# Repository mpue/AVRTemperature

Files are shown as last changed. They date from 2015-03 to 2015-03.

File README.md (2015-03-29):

AVRTemperature
==============================

Measuring temperature with the ATMega8 and a TSIC 0306. This version is interrupt driven.

Hardware: ATMega8/16MHz
 
This program measures the temperature of a TSIC0306 temperature sensor, which is
connected to the INT1 pin. The sensor itself is powered via the ZACPIN defined
in zacwire.h

At the beginning the TSIC is powered on and when the first falling edge occurs the measurement
starts. Timer 1 is started in normal mode. When the first rising edge occurs the timer is being
stopped and the value from the TCNT1 register is taken as strobe value.

From now on on each falling edge of the INT1 pin the timer1 is started in ctc mode. Each time
the OCR1A register is equal to the timer value, the TIMER1_COMPA_vect interrupt service routine
is being triggered. This is exactly the 50% duty cycle time which is needed to detect the state
of each bit.

After measuring the MSB the parity bit and the stop bit are being skipped, then the measurement
for the LSB continues, at the end the parity bit is skipped again and the measurement is complete.
The whole thing is driven by a "state machine" like mechanism. This in fact not a real state machine,
since we have no events, rules or transitions.
 
This code doesn't represent the most efficient solution. The goal was to understand the zacwire protocol
and to write human readable code. Feel free to improve the code and give suggestions.

Usage
==============================
You must have avrdude and avr-gcc installed. Use an ATMega8@16MHz, given the attached schematic.

Program with:

make program

You'll have to adjust your programmer before. Don't mess up the fuses!

Schematics and board layout resides in the eagle folder.

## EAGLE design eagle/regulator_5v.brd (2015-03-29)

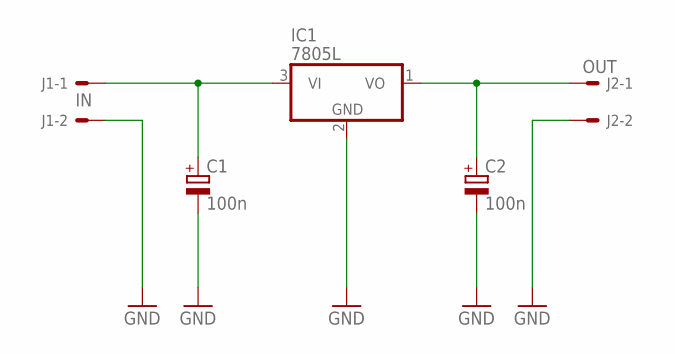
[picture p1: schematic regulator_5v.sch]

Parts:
C1, C2: 100n; TT2D5
IC1: 7805L; TO92
J1: IN; 6410-02
J2: OUT; 6410-02

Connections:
GND: C1.-, C2.-, IC1.2 (GND), J1.2, J2.2
unnamed: C1.+, IC1.3 (VI), J1.1
unnamed: C2.+, IC1.1 (VO), J2.1

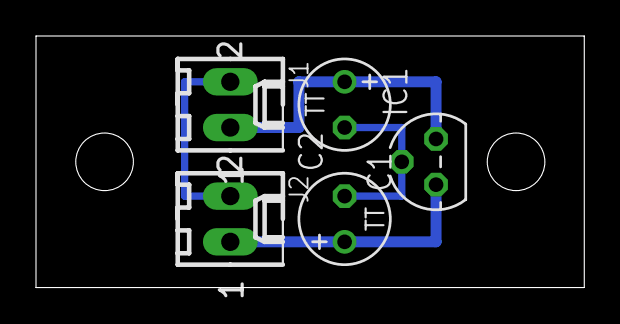
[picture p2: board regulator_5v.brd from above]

Board: 2 copper layers, 30.5 x 14.0 mm, 5 parts (0 on the bottom side), 3 nets.

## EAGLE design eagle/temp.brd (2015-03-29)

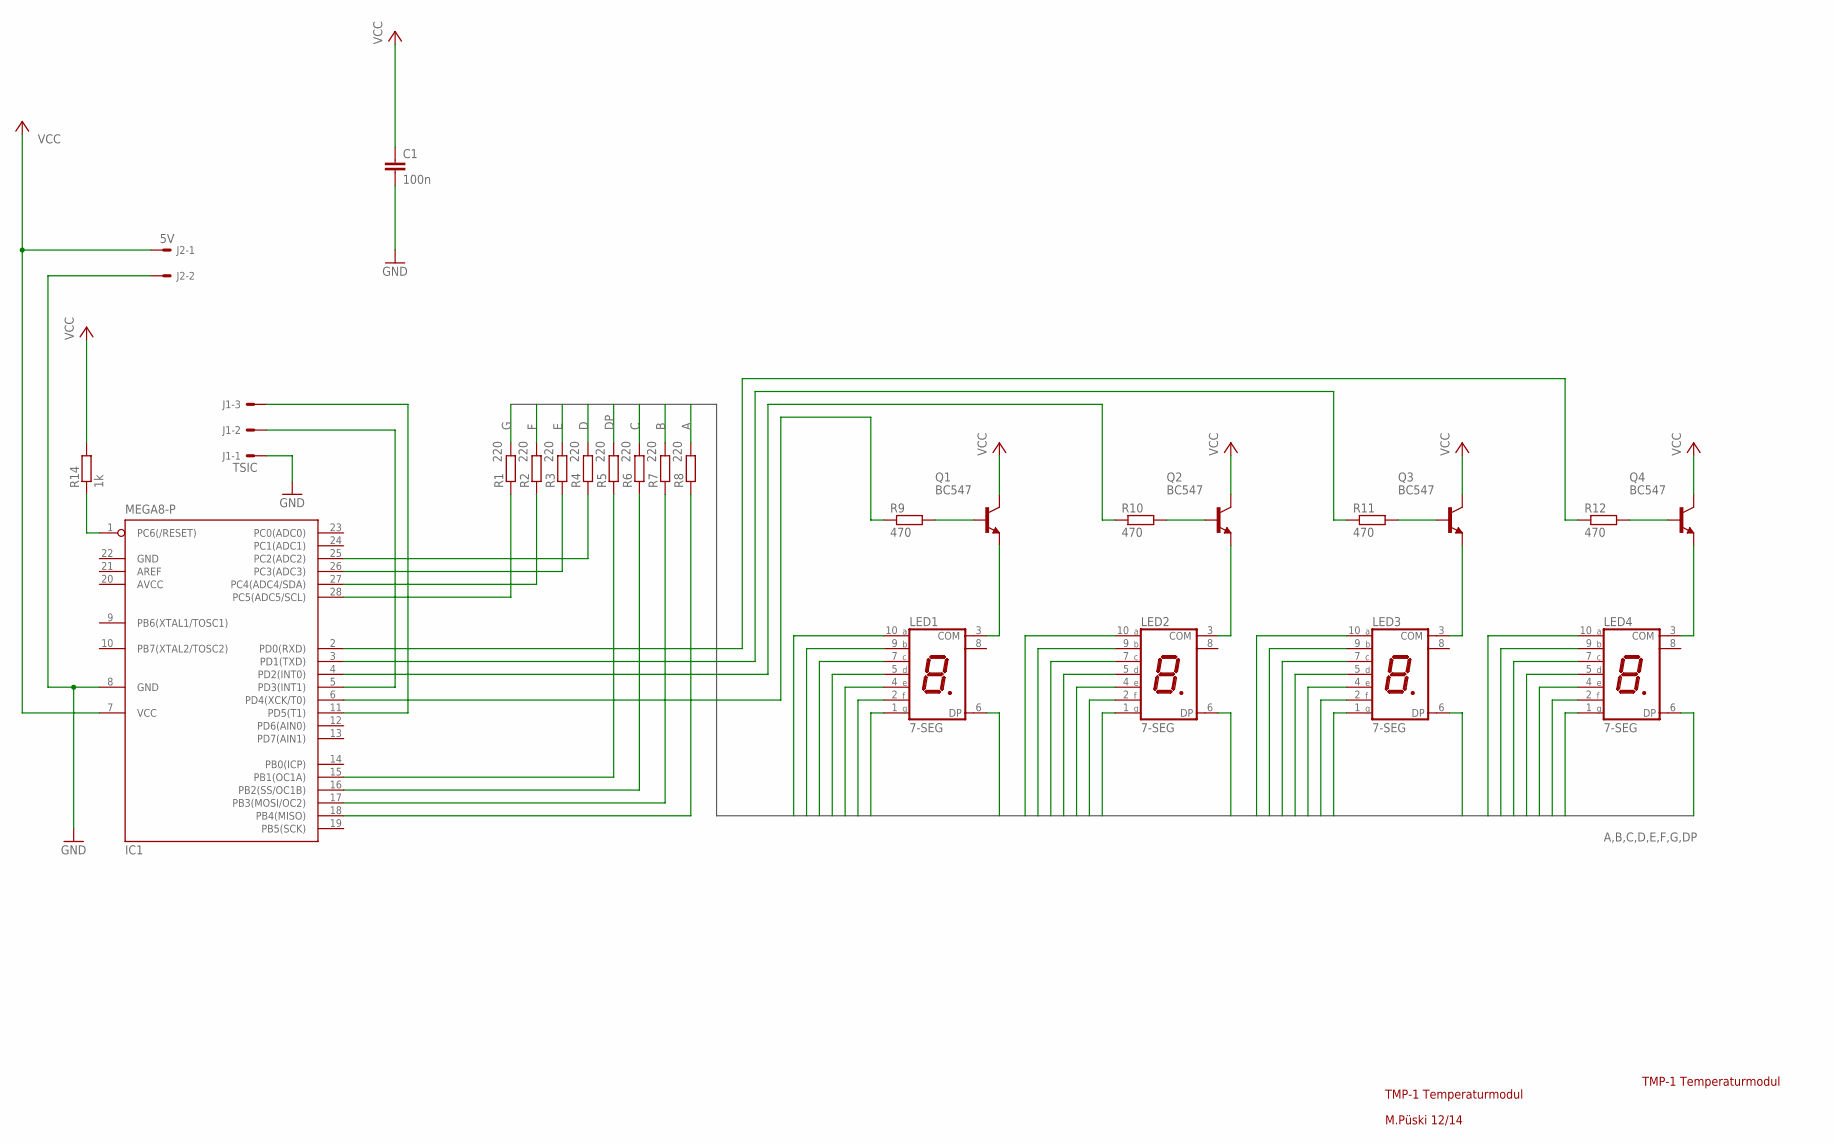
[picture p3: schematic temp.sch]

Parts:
C1: 100n; C050-024X044
IC1: MEGA8-P; DIL28-3
J1: TSIC; 6410-03
J2: 5V; 6410-02
LED1, LED2, LED3, LED4: 7-SEG; SA39-11SRWA
Q1, Q2, Q3, Q4: BC547; TO92
R1, R2, R4, R5, R6, R7, R8: 220; 0204/7
R3: 220; 0204V
R9, R10, R12: 470; 0204/7
R11: 470; 0204V
R14: 1k; 0204/7

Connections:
A: LED1.10 (A), LED2.10 (A), LED3.10 (A), LED4.10 (A), R8.2
AVCC: IC1.20 (AVCC)
B: LED1.9 (B), LED2.9 (B), LED3.9 (B), LED4.9 (B), R7.2
C: LED1.7 (C), LED2.7 (C), LED3.7 (C), LED4.7 (C), R6.2
D: LED1.5 (D), LED2.5 (D), LED3.5 (D), LED4.5 (D), R4.2
DP: LED1.6 (DP), LED2.6 (DP), LED3.6 (DP), LED4.6 (DP), R5.2
E: LED1.4 (E), LED2.4 (E), LED3.4 (E), LED4.4 (E), R3.2
F: LED1.2 (F), LED2.2 (F), LED3.2 (F), LED4.2 (F), R2.2
G: LED1.1 (G), LED2.1 (G), LED3.1 (G), LED4.1 (G), R1.2
GND: C1.2, IC1.8 (GND), IC1.22 (GND), J1.1, J2.2
unnamed: IC1.27 (PC4(ADC4/SDA)), R2.1
unnamed: IC1.26 (PC3(ADC3)), R3.1
unnamed: IC1.25 (PC2(ADC2)), R4.1
unnamed: IC1.15 (PB1(OC1A)), R5.1
unnamed: IC1.16 (PB2(SS/OC1B)), R6.1
unnamed: IC1.17 (PB3(MOSI/OC2)), R7.1
unnamed: IC1.18 (PB4(MISO)), R8.1
unnamed: Q1.2 (B), R9.2
unnamed: Q2.2 (B), R10.2
unnamed: Q3.2 (B), R11.2
unnamed: LED3.3 (COM), Q3.1 (E)
unnamed: LED2.3 (COM), Q2.1 (E)
unnamed: LED1.3 (COM), Q1.1 (E)
unnamed: IC1.2 (PD0(RXD)), R12.1
unnamed: IC1.3 (PD1(TXD)), R11.1
unnamed: IC1.4 (PD2(INT0)), R10.1
unnamed: IC1.28 (PC5(ADC5/SCL)), R1.1
unnamed: Q4.2 (B), R12.2
unnamed: LED4.3 (COM), Q4.1 (E)
unnamed: IC1.1 (PC6(/RESET)), R14.1
unnamed: IC1.6 (PD4(XCK/T0)), R9.1
unnamed: IC1.11 (PD5(T1)), J1.3
unnamed: IC1.5 (PD3(INT1)), J1.2
VCC: C1.1, IC1.7 (VCC), J2.1, Q1.3 (C), Q2.3 (C), Q3.3 (C), Q4.3 (C), R14.2

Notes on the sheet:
TMP-1 Temperaturmodul
M.Püski 12/14

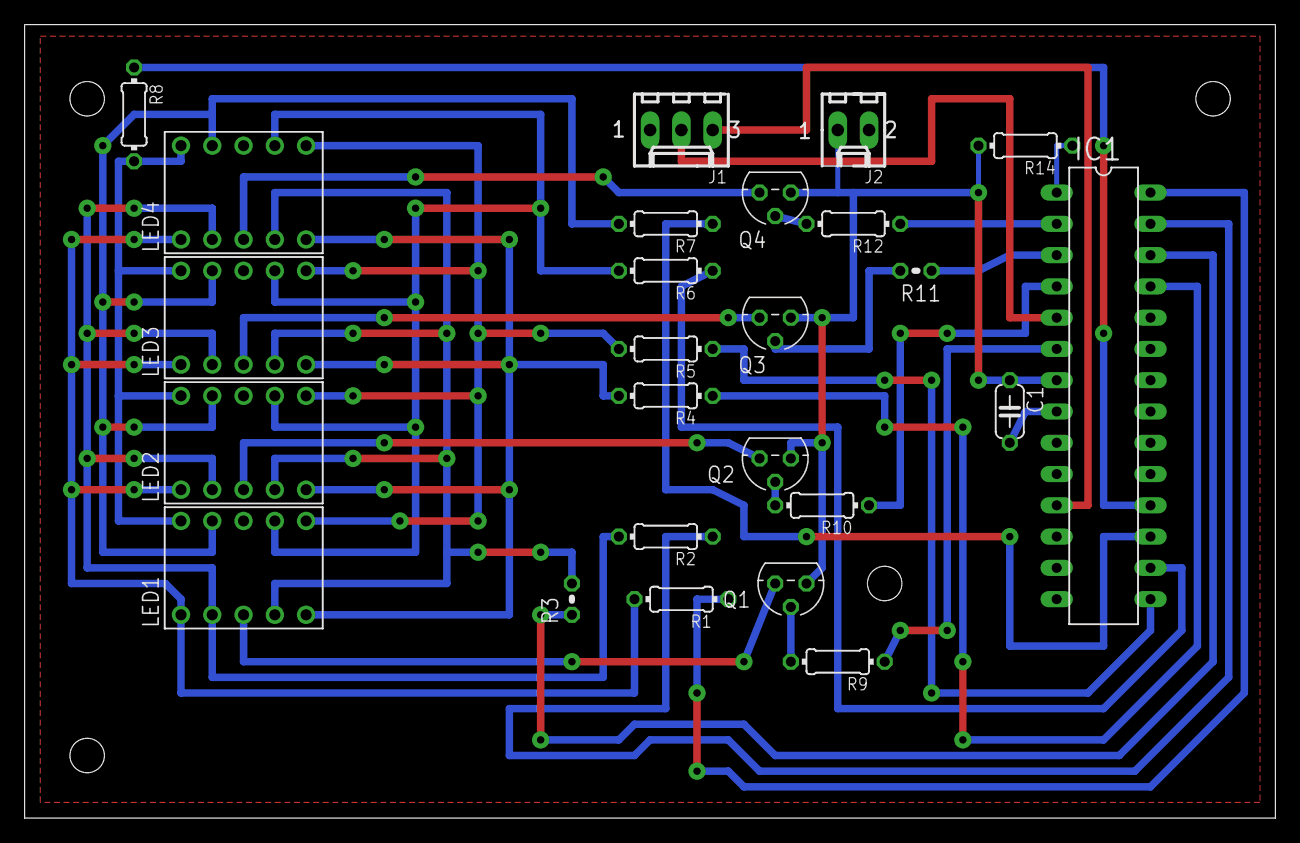
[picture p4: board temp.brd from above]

Board: 2 copper layers, 101.6 x 64.4 mm, 25 parts (0 on the bottom side), 33 nets.

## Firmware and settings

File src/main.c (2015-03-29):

/**

	ATMega and TSIC temperature measurement

	Written and maintained by Matthias Pueski

	Copyright (c) 2013 Matthias Pueski

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
*/

/**
 *	Title   : Measuring temperature with the ATMega8 and a TSIC 0306
 *	          This version is interrrupt driven
 *	Author  : Matthias Pueski
 *	File    : main.c
 *	Hardware: ATMega8/16MHz
 *
 *	DESCRIPTION :
 *
 *	This program measures the temperature of a TSIC0306 temperature sensor, which is
 *	connected to the INT1 pin. The sensor itself is powered via the ZACPIN defined
 *	in zacwire.h
 *
 *	At the beginning the TSIC is powered on and when the first falling edge occurs the measurement
 *	starts. Timer 1 is started in normal mode. When the first rising edge occurs the timer is being
 *	stopped and the value from the TCNT1 register is taken as strobe value.
 *	From now on on each falling edge of the INT1 pin the timer1 is started in ctc mode.	Each time
 *	the OCR1A register is equal to the timer value, the TIMER1_COMPA_vect interrupt	service routine
 *	is being triggered. This is exactly the 50% duty cycle time which is needed to detect the state
 *	of each bit.
 *	After measuring the MSB the parity bit and the stop bit are being skipped, then the measurement
 *	for the LSB continues, at the end the parity bit is skipped again and the measurement is complete.
 *	The whole thing is driven by a "state machine" like mechanism. This in fact not a real state machine,
 *	since we have no events, rules or transitions.
 *
 *  This code doesn't represent the most efficient solution. The goal was to understand the zacwire protocol
 *	and to write human readable code. Feel free to improve the code and give suggestions.
 *
 *	Author : Matthias Pueski (pueski@gmx.de)
 *
 */
#ifndef F_CPU
#define F_CPU 8000000L
#endif

#include <avr/io.h>
#include <avr/wdt.h>
#include <avr/interrupt.h>
#include <util/delay.h>
#include <avr/eeprom.h>
#include <avr/pgmspace.h>
#include "zacwire.h"
#include "int_ctrl.h"
#include "timer_ctrl.h"

#define MUXDELAY 5

// initial state of the reading "state machine"
zacstate state = ZAC_READING_START_BIT_LOW;
// half the value of tstrobe
volatile uint16_t strobe = 0;
// high byte of a zacwire packet
volatile uint8_t zac_high_byte = 0;
// low byte of a zacwire packet
volatile uint8_t zac_low_byte = 0;
// the bit number of the byte currently being read including parity
volatile uint8_t zac_current_bit = 8;
// output buffer
volatile uint8_t buffer[2] = {0};

#define setPin(PORT,PIN) PORT |= (1 << PIN)
#define clearPin(PORT,PIN) PORT &= ~(1 << PIN)

typedef uint8_t bool;

#define true 1
#define false 0


// interrupt service routine for the timer1 ctc
ISR (TIMER1_COMPA_vect) {

	// stop the counter and reset timer count
	timer1_stop_ctc();
	TCNT1 = 0;

	// reading the HIGH byte of a zacwire packet
	if (state == ZAC_READING_HIGH_BYTE) {
		// read bits ignoring the last bit (parity)
		// actually reading 9 bits in total
		if (PIND & (1 << PIND3)) {
			if (zac_current_bit > 0) {
				zac_high_byte |= (1 << (zac_current_bit - 1));
			}
		}
		// decrement current bit every trigger
		if (zac_current_bit > 0) {
			zac_current_bit--;
		}
		// have read all bits from HIGH byte, switch
		// to LOW byte
		else {
			state = ZAC_READING_LOW_BYTE;
			// now we have one bit more since there comes another stop bit
			zac_current_bit = 9;
		}
	}

	// after reading the parity bit of the first byte, we can omit
	// the stop bit, since the next falling edge does not
	// happen until the next start bit (LOW byte)

	// reading the LOW byte of a zacwire packet
	else if (state == ZAC_READING_LOW_BYTE) {
		// read bits ignoring the first bit (start bit) and the last bit (parity)
		// actually reading 10 bits in total
		if (PIND & (1 << PIND3)) {
			if (zac_current_bit > 0 && zac_current_bit < 9) {
				zac_low_byte |= (1 << (zac_current_bit - 1));
			}
		}
		// decrement current bit every trigger
		if (zac_current_bit > 0) {
			zac_current_bit--;
		}
		// all bits read => back to the beginning
		else {
			zac_current_bit = 8;
			state = ZAC_READING_START_BIT_LOW;
		}
	}
}

// Interrupt service routine for the int1 pin
ISR (INT1_vect) {
	/**
	 * Beginning of zacwire packet, first falling edge
	 * start measuring tstrobe time
	 */
	if (state == ZAC_READING_START_BIT_LOW) {
		// if there was on measurement cycle, store data
		// from zacwire in usb transfer buffer
		if (zac_high_byte >= 0)
			buffer[0] = zac_high_byte;
		if (zac_low_byte >= 0)
			buffer[1] = zac_low_byte;
		// reset measured values
		zac_high_byte = 0;
		zac_low_byte = 0;
		// start timer1 and use rising edge for int1
		// if the next rising edge happens this is the second half of the start bit
		int1_switch_rising_edge();
		timer1_start_normal();
		state = ZAC_READING_START_BIT_HIGH;
	}
	else if (state == ZAC_READING_START_BIT_HIGH) {
		// rising edge of the start bit
		// at this stage the first rising edge of the start bit happened
		// we now have the strobe time acquired
		timer1_stop();
		strobe = TCNT1;
		// select falling edge, thus the startbit is complete
		// on next falling edge
		int1_switch_falling_edge();
		// next stage
		state = ZAC_ACQUIRING_TSTROBE;
	}
	else if (state == ZAC_ACQUIRING_TSTROBE) {
		// falling edge of start bit occured, reset timer count
		TCNT1 = 0;
		// start timer 1 in ctc mode, timer interrupt then occurs
		// each tstrobe/2 (50% duty cycle)
		timer1_start_ctc(strobe);
		// we now start reading the first byte
		state = ZAC_READING_HIGH_BYTE;
	}
	// now we are reading either the MSB or the LSB, start timer1 in ctc mode each falling edge
	else if (state == ZAC_READING_HIGH_BYTE || state == ZAC_READING_LOW_BYTE) {
		TCNT1 = 0;
		timer1_start_ctc(strobe);
	}
}

void displayNumber(uint8_t num, bool withDot) {

	setPin(PORTC, 5);
	setPin(PORTC, 4);
	setPin(PORTC, 3);
	setPin(PORTC, 2);
	setPin(PORTB, 4);
	setPin(PORTB, 3);
	setPin(PORTB, 2);
	setPin(PORTB, 1);

	if (withDot) {
		clearPin(PORTB, 1);
	}

	if (num == 0) {
		clearPin(PORTC, 4);
		clearPin(PORTC, 3);
		clearPin(PORTC, 2);
		clearPin(PORTB, 4);
		clearPin(PORTB, 3);
		clearPin(PORTB, 2);
	}
	else if (num == 1) {
		clearPin(PORTB, 3);
		clearPin(PORTB, 2);
	}
	else if (num == 2) {
		clearPin(PORTC, 5);
		clearPin(PORTC, 3);
		clearPin(PORTC, 2);
		clearPin(PORTB, 4);
		clearPin(PORTB, 3);
	}
	else if (num == 3) {
		clearPin(PORTC, 5);
		clearPin(PORTC, 2);
		clearPin(PORTB, 4);
		clearPin(PORTB, 3);
		clearPin(PORTB, 2);
	}
	else if (num == 4) {
		clearPin(PORTC, 5);
		clearPin(PORTC, 4);
		clearPin(PORTB, 3);
		clearPin(PORTB, 2);
	}
	else if (num == 5) {
		clearPin(PORTC, 5);
		clearPin(PORTC, 4);
		clearPin(PORTC, 2);
		clearPin(PORTB, 4);
		clearPin(PORTB, 2);
	}
	else if (num == 6) {
		clearPin(PORTC, 5);
		clearPin(PORTC, 4);
		clearPin(PORTC, 3);
		clearPin(PORTC, 2);
		clearPin(PORTB, 4);
		clearPin(PORTB, 2);
	}
	else if (num == 7) {
		clearPin(PORTB, 4);
		clearPin(PORTB, 3);
		clearPin(PORTB, 2);
	}
	else if (num == 8) {
		clearPin(PORTC, 5);
		clearPin(PORTC, 4);
		clearPin(PORTC, 3);
		clearPin(PORTC, 2);
		clearPin(PORTB, 4);
		clearPin(PORTB, 3);
		clearPin(PORTB, 2);
	}
	else if (num == 9) {
		clearPin(PORTC, 5);
		clearPin(PORTC, 4);
		clearPin(PORTC, 2);
		clearPin(PORTB, 4);
		clearPin(PORTB, 3);
		clearPin(PORTB, 2);
	}

}

void displayMinus(void) {

	setPin(PORTC, 5);
	setPin(PORTC, 4);
	setPin(PORTC, 3);
	setPin(PORTC, 2);
	setPin(PORTB, 4);
	setPin(PORTB, 3);
	setPin(PORTB, 2);
	setPin(PORTB, 1);

	clearPin(PORTC, 5);
}

void displayNothing(void) {

	setPin(PORTC, 5);
	setPin(PORTC, 4);
	setPin(PORTC, 3);
	setPin(PORTC, 2);
	setPin(PORTB, 4);
	setPin(PORTB, 3);
	setPin(PORTB, 2);
	setPin(PORTB, 1);
}

void selectSegment(uint8_t num){

	if (num == 0) {
		setPin(PORTD, 0);
		clearPin(PORTD, 1);
		clearPin(PORTD, 2);
		clearPin(PORTD, 4);
	}
	else if (num == 1) {
		clearPin(PORTD, 0);
		setPin(PORTD, 1);
		clearPin(PORTD, 2);
		clearPin(PORTD, 4);

	}
	else if (num == 2) {
		clearPin(PORTD, 0);
		clearPin(PORTD, 1);
		setPin(PORTD, 2);
		clearPin(PORTD, 4);
	}
	else if (num == 3) {
		clearPin(PORTD, 0);
		clearPin(PORTD, 1);
		clearPin(PORTD, 2);
		setPin(PORTD, 4);
	}

}

void displayMeasure(float value) {

	int val;

	bool minus = false;

	if (value < 0) {
		minus = true;
		value = value * - 1;
	}

	if (value < 1) {
		val = value * 1000;
	}
	else if (value < 10) {
		val = value * 100;
	}
	else if (value < 100){
		val = value * 10;
	}
	else {
		val = value;
	}

	int hundreds = val / 100;
	int tenths = (val - hundreds * 100) / 10;
	int ones = val - (hundreds * 100) - (tenths * 10);

	selectSegment(0);
	displayNumber(ones, false);
	_delay_ms(MUXDELAY);

	selectSegment(1);

	if (value < 1)
		displayNumber(tenths, false);
	else if (value < 10)
		displayNumber(tenths, false);
	else if (value < 100)
		displayNumber(tenths, true);
	else
		displayNumber(tenths, false);
	_delay_ms(MUXDELAY);

	selectSegment(2);

	if (value < 1)
		displayNumber(hundreds, false);
	else if (value < 10)
		displayNumber(hundreds, true);
	else if (value < 100)
		displayNumber(hundreds, false);
	else
		displayNumber(hundreds, false);

	_delay_ms(MUXDELAY);

	selectSegment(3);

	if (minus) {
		displayMinus();
	}
	else {
		displayNothing();
	}

	_delay_ms(MUXDELAY);

}

int main(void) {

	DDRC |= 1 << DDC5;
	DDRC |= 1 << DDC4;
	DDRC |= 1 << DDC3;
	DDRC |= 1 << DDC2;
//
	DDRB = 0xFF;
	PORTB = 0xFF;

//
	DDRD |= 1 << DDD0;
	DDRD |= 1 << DDD1;
	DDRD |= 1 << DDD2;
	DDRD |= 1 << DDD4;
	DDRD |= 1 << DDD5;
//
	int1_enable();
	int1_select_falling_edge();
//	// turn TSIC on
//	//zac_on();
//
	setPin(PORTD, 5);
//
	_delay_us(125);
	// enable interrupts
	sei();
	// for temperature calculations
	uint16_t temperature = 0;
	float value = 0.0f;
//
	// main loop
	for(;;) {

		temperature = (buffer[0] << 8) | buffer [1];
		value = ((float)temperature / 2047 * 200) - 50;

		// display value
		displayMeasure(value);

	}
	// never happens, just to make the compiler happy



	return 0;
}

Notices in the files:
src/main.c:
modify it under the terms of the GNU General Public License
